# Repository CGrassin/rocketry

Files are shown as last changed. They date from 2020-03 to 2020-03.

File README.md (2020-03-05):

# Charleslab's rocketery

Thrust vectoring is the ability of an aircraft, rocket, or other vehicle to manipulate the direction of the thrust from its motor in order to control the attitude (angle) of the vehicle. It is used in rocketry it is the primary means of attitude control, as aerodynamic control surfaces are ineffective outside the atmosphere.

This repository contains all resources for my model rocketery experiments. The content of each folder is described hereunder.

Everything is work in progress (currently working on the code and the gimbal).

## 3D models

This folder contains the 3D models for my rocket:
* The 2 axes thrust vectoring control (TVC) gimbal (SolidWorks),
* The gimbal test stand (OpenSCAD parametric design),
* The PCB holder (OpenSCAD parametric design),
* The nose cone (OpenSCAD parametric design).

TODO : add render of all models

The gimbal is a 3D-printable, parametric Solidworks model. There are two variables that should be adjusted to fit your needs: the diameter of the rocket motor and the diameter of the rocket body. The geometry adapts to these constraints. It should be 3D-printed with supports enabled.

TODO : add photo

The cone is a work-in-progress parametric openSCAD model.

## Electronics

The "Sagan" PCB is my rocket's onboard computer. It features:
* Arduino Mini (ATMega328P at 3.3v),
* BMP280 barometer,
* MPU6050 gyroscope and accelerometer,
* Micro SD Card reader to store in-flight telemetry,
* 3 servo outputs (X, Y and extra),
* 2 pyro channels (PYRO0 and PYRO1),
* LED and buzzer.

TODO : add picture

Designed in KiCad.

## Code

This folder contains the Arduino code for the "Sagan" PCB.

To tune and test the controller, I made a Java gimbaled rocket simulator: http://charleslabs.fr/en/project-Gimbaled+Model+Rocket+Simulator

## Flight data

This folder holds the data (telemetry) for each flight of the rocket.

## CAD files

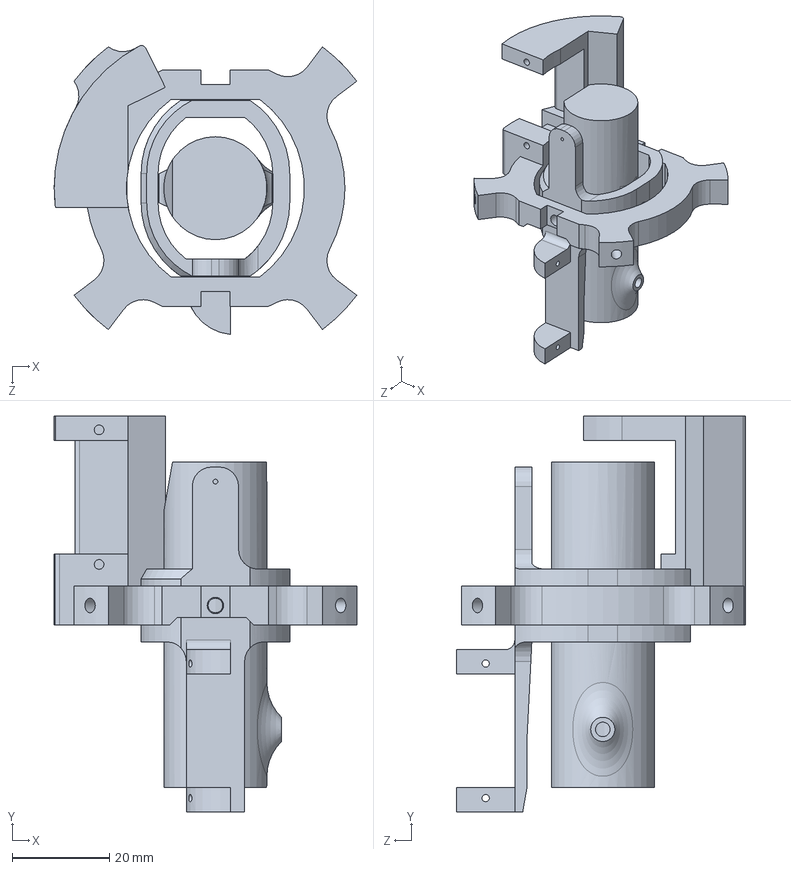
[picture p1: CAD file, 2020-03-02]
3D_models/KeplerMK1_TVC.SLDPRT
62.3 x 81.5 x 59.5 mm

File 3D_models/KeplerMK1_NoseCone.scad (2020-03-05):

/**
* Nose cones for model rockets.
*
* Units: mm
*
* CGrassin, 2020, MIT License, based on
* NOSE CONE LIBRARY, version 1.0
* by Garrett Goss, 2015, published 9/16, public domain.
**/

// --- Settings ---
rocket_diameter = 73;
c_factor = 0/3;
cone_length = 100;
base_length=8;

cylinder(base_length,d=rocket_diameter,$fn=500);
translate([0, 0,base_length]) cone_haack(C = c_factor, R = rocket_diameter/2, L = cone_length - base_length, s = 200);

// --- Code ---
module cone_cone(R = 5, L = 10, s = 500){
// CONICAL NOSE CONE
//
// Formula: y = x * R / L; 
//
//     but there's an easier way...

echo(str("CONICAL NOSE CONE"));    
echo(str("R = ", R)); 
echo(str("L = ", L)); 
echo(str("s = ", s)); 

cylinder(h = L, r1 = R, r2 = 0, center = false, $fn = s);
    
}

module cone_blunted(R = 5, R_nose = 2, L = 15, s = 500){
// SPHERICALLY BLUNTED CONE
//     A conical nose capped with a segment of a sphere
//

echo(str("SPHERICALLY BLUNTED CONE"));
echo(str("R = ", R));
echo(str("R_nose = ", R_nose)); 
echo(str("L = ", L));
echo(str("s = ", s)); 
    
x_t = (pow(L,2) / R) * sqrt(pow(R_nose,2) / (pow(R,2) + pow(L,2)));
y_t = x_t * (R/L);
x_o = x_t + sqrt(pow(R_nose,2) - pow(y_t,2));
x_a = x_o - R_nose;

TORAD = PI/180;
TODEG = 180/PI;
inc = 1/s;
    
s_x_t = round((s * x_t) / L);

rotate_extrude(convexity = 10, $fn = s)
union(){
    for (i = [s_x_t : s]){

        x_last = L * (i - 1) * inc;
        x = L * i * inc;

        y_last = x_last * (R/L);

        y = x * (R / L);

        rotate([0, 0, -90]) polygon(points = [[x_last - L, 0], [x - L, 0], [x - L, y], [x_last - L, y_last]], convexity = 10);
    }

    translate([0, L-x_o, 0]) difference(){
        circle(R_nose, $fn = s);
        translate([-R_nose, 0, 0]) square((2 * R_nose), center = true);
    }
}
}
        
module cone_parabolic(R = 5, L = 10, K = 0.5, s = 500){
// PARABOLIC NOSE CONE
//
// Formula: y = R * ((2 * (x / L)) - (K * pow((x / L),2)) / (2 - K);
//
// Parameters:
// K = 0 for cone
// K = 0.5 for 1/2 parabola
// K = 0.75 for 3/4 parabola
// K = 1 for full parabola

echo(str("PARABOLIC NOSE CONE"));
echo(str("R = ", R)); 
echo(str("L = ", L)); 
echo(str("K = ", K)); 
echo(str("s = ", s)); 
    
if (K >= 0 && K <= 1){

    inc = 1/s;

    rotate_extrude(convexity = 10, $fn = s)
    for (i = [1 : s]){
        
        x_last = L * (i - 1) * inc;
        x = L * i * inc;

        y_last = R * ((2 * ((x_last)/L)) - (K * pow(((x_last)/L), 2))) / (2 - K);
        y = R * ((2 * (x/L)) - (K * pow((x/L), 2))) / (2 - K);

        polygon(points = [[y_last, 0], [y, 0], [y, L - x], [y_last, L - x_last]], convexity = 10);
    }
} else echo(str("ERROR: K = ", K, ", but K must fall between 0 and 1 (inclusive)."));
}

module cone_haack(C = 0, R = 5, L = 10, s = 500){

// SEARS-HAACK BODY NOSE CONE:
//
// Parameters:
// C = 1/3: LV-Haack (minimizes supersonic drag for a given L & V)
// C = 0: LD-Haack (minimizes supersonic drag for a given L & D), also referred to as Von Kármán
//
// Formulae (radians):
// theta = acos(1 - (2 * x / L));
// y = (R / sqrt(PI)) * sqrt(theta - (sin(2 * theta) / 2) + C * pow(sin(theta),3));

echo(str("SEARS-HAACK BODY NOSE CONE"));
echo(str("C = ", C)); 
echo(str("R = ", R)); 
echo(str("L = ", L)); 
echo(str("s = ", s)); 

TORAD = PI/180;
TODEG = 180/PI;

inc = 1/s;

rotate_extrude(convexity = 10, $fn = s)
for (i = [1 : s]){
    x_last = L * (i - 1) * inc;
    x = L * i * inc;

    theta_last = TORAD * acos((1 - (2 * x_last/L)));
    y_last = (R/sqrt(PI)) * sqrt(theta_last - (sin(TODEG * (2*theta_last))/2) + C * pow(sin(TODEG * theta_last), 3));

    theta = TORAD * acos(1 - (2 * x/L));
    y = (R/sqrt(PI)) * sqrt(theta - (sin(TODEG * (2 * theta)) / 2) + C * pow(sin(TODEG * theta), 3));

    rotate([0, 0, -90]) polygon(points = [[x_last - L, 0], [x - L, 0], [x - L, y], [x_last - L, y_last]], convexity = 10);
}
}


module cone_power_series(n = 0.5, R = 5, L = 10, s = 500){
// POWER SERIES NOSE CONE:
//
// Formula: y = R * pow((x / L), n) for 0 <= n <= 1
//
// Parameters:
// n = 1 for a cone
// n = 0.75 for a 3/4 power
// n = 0.5 for a 1/2 power (parabola)
// n = 0 for a cylinder

echo(str("POWER SERIES NOSE CONE"));
echo(str("n = ", n)); 
echo(str("R = ", R)); 
echo(str("L = ", L)); 
echo(str("s = ", s)); 

inc = 1/s;

rotate_extrude(convexity = 10, $fn = s)
for (i = [1 : s]){

    x_last = L * (i - 1) * inc;
    x = L * i * inc;

    y_last = R * pow((x_last/L), n);
    y = R * pow((x/L), n);

    rotate([0, 0, 90]) polygon(points = [[0,y_last],[0,y],[L-x,y],[L-x_last,y_last]], convexity = 10);
}
}

module cone_elliptical(n = 0.5, R = 5, L = 10, s = 500){
// ELLIPTICAL NOSE CONE:
//
// Formula: y = R * sqrt(1 - pow((x / L), 2));

echo(str("ELLIPTICAL NOSE CONE"));    
echo(str("n = ", n)); 
echo(str("R = ", R)); 
echo(str("L = ", L)); 
echo(str("s = ", s)); 

inc = 1/s;

rotate_extrude(convexity = 10, $fn = s)
for (i = [1 : s]){

    x_last = L * (i - 1) * inc;
    x = L * i * inc;

    y_last = R * sqrt(1 - pow((x_last/L), 2));
    y = R * sqrt(1 - pow((x/L), 2));

    rotate([0,0,90]) polygon(points = [[0, y_last], [0, y], [x, y], [x_last, y_last]], convexity = 10);
}
}
module cone_ogive_sec(rho = 8, R = 5, L = 10, s = 500){
// SECANT OGIVE NOSE CONE:
//
// For a bulging cone (e.g. Honest John): L/2 < rho < (R^2 + L^2)/(2R)
// Otherwise: rho > (R^2 + L^2)/(2R)
//
// Formulae:
// alpha = TORAD * atan(R/L) - TORAD * acos(sqrt(pow(L,2) + pow(R,2)) / (2 * rho));
// y = sqrt(pow(rho,2) - pow((rho * cos(TODEG * alpha) - x),2)) + (rho * sin(TODEG * alpha));

echo(str("SECANT OGIVE NOSE CONE"));    
echo(str("rho = ", rho)); 
echo(str("R = ", R)); 
echo(str("L = ", L)); 
echo(str("s = ", s)); 

TORAD = PI/180;
TODEG = 180/PI;
    
inc = 1/s;

alpha = TORAD * atan(R/L) - TORAD * acos(sqrt(pow(L,2) + pow(R,2)) / (2*rho));

rotate_extrude(convexity = 10, $fn = s)
for (i = [1 : s]){

    x_last = L * (i - 1) * inc;
    x = L * i * inc;

    y_last = sqrt(pow(rho,2) - pow((rho * cos(TODEG*alpha) - x_last), 2)) + (rho * sin(TODEG*alpha));

    y = sqrt(pow(rho,2) - pow((rho * cos(TODEG*alpha) - x), 2)) + (rho * sin(TODEG*alpha));

    rotate([0, 0, -90]) polygon(points = [[x_last - L, 0], [x - L, 0], [x - L, y], [x_last - L, y_last]], convexity = 10);
}
}


module cone_ogive_tan(R = 5, L = 10, s = 500){
// TANGENT OGIVE
//
//

echo(str("TANGENT OGIVE"));    
echo(str("R = ", R)); 
echo(str("L = ", L)); 
echo(str("s = ", s)); 

rho = (pow(R,2) + pow(L,2)) / (2 * R);

inc = 1/s;

rotate_extrude(convexity = 10, $fn = s)
for (i = [1 : s]){
    x_last = L * (i - 1) * inc;
    x = L * i * inc;

    y_last = sqrt(pow(rho,2) - pow((L - x_last), 2)) + R - rho;

    y = sqrt(pow(rho,2) - pow((L - x), 2)) + R - rho;

    rotate([0, 0, -90]) polygon(points = [[x_last - L, 0], [x - L, 0], [x - L, y], [x_last - L, y_last]], convexity = 10);
}
}

module cone_ogive_tan_blunted(R_nose = 2, R = 5, L = 10, s = 500){
// SPHERICALLY BLUNTED TANGENT OGIVE
//
//

echo(str("SPHERICALLY BLUNTED TANGENT OGIVE"));    
echo(str("R_nose = ", R_nose)); 
echo(str("R = ", R)); 
echo(str("L = ", L)); 
echo(str("s = ", s)); 

rho = (pow(R,2) + pow(L,2)) / (2*R);

x_o = L - sqrt(pow((rho - R_nose), 2) - pow((rho - R), 2));
x_a = x_o - R_nose;
y_t = (R_nose * (rho - R)) / (rho - R_nose);
x_t = x_o - sqrt(pow(R_nose, 2)- pow(y_t, 2));

TORAD = PI/180;
TODEG = 180/PI;
    
inc = 1/s;
    
s_x_t = round((s * x_t) / L);

alpha = TORAD * atan(R/L) - TORAD * acos(sqrt(pow(L,2) + pow(R,2)) / (2*rho));

rotate_extrude(convexity = 10, $fn = s) union(){
    for (i=[s_x_t:s]){

        x_last = L * (i - 1) * inc;
        x = L * i * inc;

        y_last = sqrt(pow(rho,2) - pow((rho * cos(TODEG * alpha) - x_last),2)) + (rho * sin(TODEG * alpha));

        y = sqrt(pow(rho,2) - pow((rho * cos(TODEG * alpha) - x),2)) + (rho * sin(TODEG * alpha));

        rotate([0,0,-90])polygon(points = [[x_last-L,0],[x-L,0],[x-L,y],[x_last-L,y_last]], convexity = 10);
    }

    translate([0, L - x_o, 0]) difference(){
        circle(R_nose, $fn = s);
        translate([-R_nose, 0, 0]) square((2 * R_nose), center = true);
    }
}
}

module cone_biconic(R = 5, R_nose = 3, L1 = 6, L2 = 4, s = 500){

echo(str("BICONIC NOSE CONE")); 
echo(str("R = ", R));    
echo(str("R_nose = ", R_nose)); 
echo(str("L1 = ", L1));
echo(str("L2 = ", L2)); 
echo(str("s = ", s)); 
    
L = L1 + L2;
s_intermediate = s * (L2/L);
inc = 1/s;

rotate_extrude(convexity = 10, $fn = s) translate([0, L, 0]) rotate([0, 0, -90])
union(){
    for (i = [1 : s_intermediate]){

        x_last = L * (i - 1) * inc;
        x = L * i * inc;

        y_last = x_last * (R_nose/L2);
        y = x * (R_nose/L2);

        polygon(points = [[x_last, 0], [x_last, y_last], [x, y], [x, 0]], convexity = 10);
    }
    
    for (i=[s_intermediate:s]){

        x_last = L * (i - 1) * inc;
        x = L * i * inc;

        y_last = R_nose + ((x_last - L2) * (R - R_nose)) / L1;
        y = R_nose + ((x - L2) * (R - R_nose)) / L1;
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

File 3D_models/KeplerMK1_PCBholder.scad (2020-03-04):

/**
* PCB holder for model rockets.
* Use with "Sagan" PCB.
*
* Units: mm
*
* CGrassin, 2020, MIT License
**/

// --- Settings ---
// Inside diameter of the rocket's body (in mm).
rocket_diameter = 70;

// --- Code ---
rocket_PCB_holder(rocket_diameter);


module rocket_PCB_holder(rocket_diameter) {
    // --- Internal variables ---
    //PCB
    PCB_holes_diameter = 3.2;
    PCB_holes_spacing = 32.51;
    //Ring
    ring_width = 1.5;
    ring_heigth = 6;
    //Screw blocks
    screw_block_nb = 2;
    screw_block_width = 5;
    screw_block_taper = 2.5;
    screw_block_length = 6;
    screw_block_diameter = 3;

    // --- Computed variables ---
    a = sqrt(pow(rocket_diameter/2,2)-pow((screw_block_width+2*screw_block_taper)/2,2))-screw_block_length/2;

    // Ring
    difference() {
        union(){
            // Main tube
            difference() {
                cylinder(ring_heigth,d=rocket_diameter,center=true,$fn=200);
                cylinder(ring_heigth+1,d=rocket_diameter-ring_width*2,center=true,$fn=200);
            }
            
            // Screw blocks
           for(i = [0:360/screw_block_nb:360]) rotate([0, 0, i]) 
               translate([0,a,0]) 
               linear_extrude(ring_heigth,center=true)
               translate([-screw_block_width/2,-screw_block_length/2,0]) 
               polygon(points=[[0,0],[-screw_block_taper,screw_block_length],[screw_block_width+screw_block_taper,screw_block_length],[screw_block_width,0]]);
        }
        
        // Screw blocks hole
        for(i = [0:360/screw_block_nb:360]) rotate([0, 0, i]) translate([0,a,0]) rotate([90, 0, 0]) cylinder(screw_block_length+3, d=screw_block_diameter, $fn=20, center=true);
    }

    // Central bar
    difference() {
        cube([rocket_diameter, ring_width, ring_heigth],center=true);
        
        for(i = [-PCB_holes_spacing/2,PCB_holes_spacing/2])
            translate([i,0,0]) rotate([90, 0, 0]) cylinder(ring_width+1,d=PCB_holes_diameter,$fn=100,center=true);
    }
}

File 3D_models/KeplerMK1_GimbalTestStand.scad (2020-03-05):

/**
* Gimbal test stand for model rockets.
*
* Units: mm
*
* CGrassin, 2020, MIT License
**/

// --- Settings ---
// Inside diameter of the rocket's body (in mm).
rocket_diameter = 70;

// --- Code ---
rocket_test_stand(rocket_diameter);

module rocket_test_stand(rocket_diameter,stand_height=55,base_screw_holes=true) {
    // Internal variables
    stand_width = 3;
    stand_base_height = 2;
    stand_base_diameter = stand_width + 15;
    stand_taper_base = 2;
    screw_holes_dia = 3.2;
    
    difference(){
        // Main body (tube)
        union(){
            // Main truncated cone shape
            cylinder(stand_height, d1=rocket_diameter+stand_width+stand_taper_base*2,d2=rocket_diameter+stand_width,$fn=200);
            
            // Base ring
            cylinder(stand_base_height, d=rocket_diameter+stand_base_diameter,$fn=200);
            
            // Chamfer
            translate([0,0,stand_base_height]) cylinder(stand_base_height+10, d1=rocket_diameter+stand_base_diameter,d2=rocket_diameter,$fn=200);
        }
        // Inside
        cylinder(stand_height+1, d=rocket_diameter,$fn=100);
        
        // Gimbal screw holes
        for(i = [0:90:360])
        rotate([0,0,i]) translate([0, 0, stand_height-1.5*screw_holes_dia]) rotate([0, 90, 0]) cylinder(rocket_diameter, d=screw_holes_dia,$fn=20);
        
        // Remove side material
        cut = rocket_diameter/3.2;
        for(i = [45:90:360]) translate([0,0,stand_base_height]) rotate([0, -90, i]) linear_extrude(rocket_diameter) polygon([[0,-cut],[0,cut],[stand_height,cut],[stand_height,-cut]]);
        
        // Base screw holes
        if(base_screw_holes) {
            for(i = [45:90:360]) rotate([0,0,i]) translate([(rocket_diameter+stand_base_diameter/2)/2,0,0]) cylinder(stand_base_height,d=screw_holes_dia,$fn=20);
        }
    }
}

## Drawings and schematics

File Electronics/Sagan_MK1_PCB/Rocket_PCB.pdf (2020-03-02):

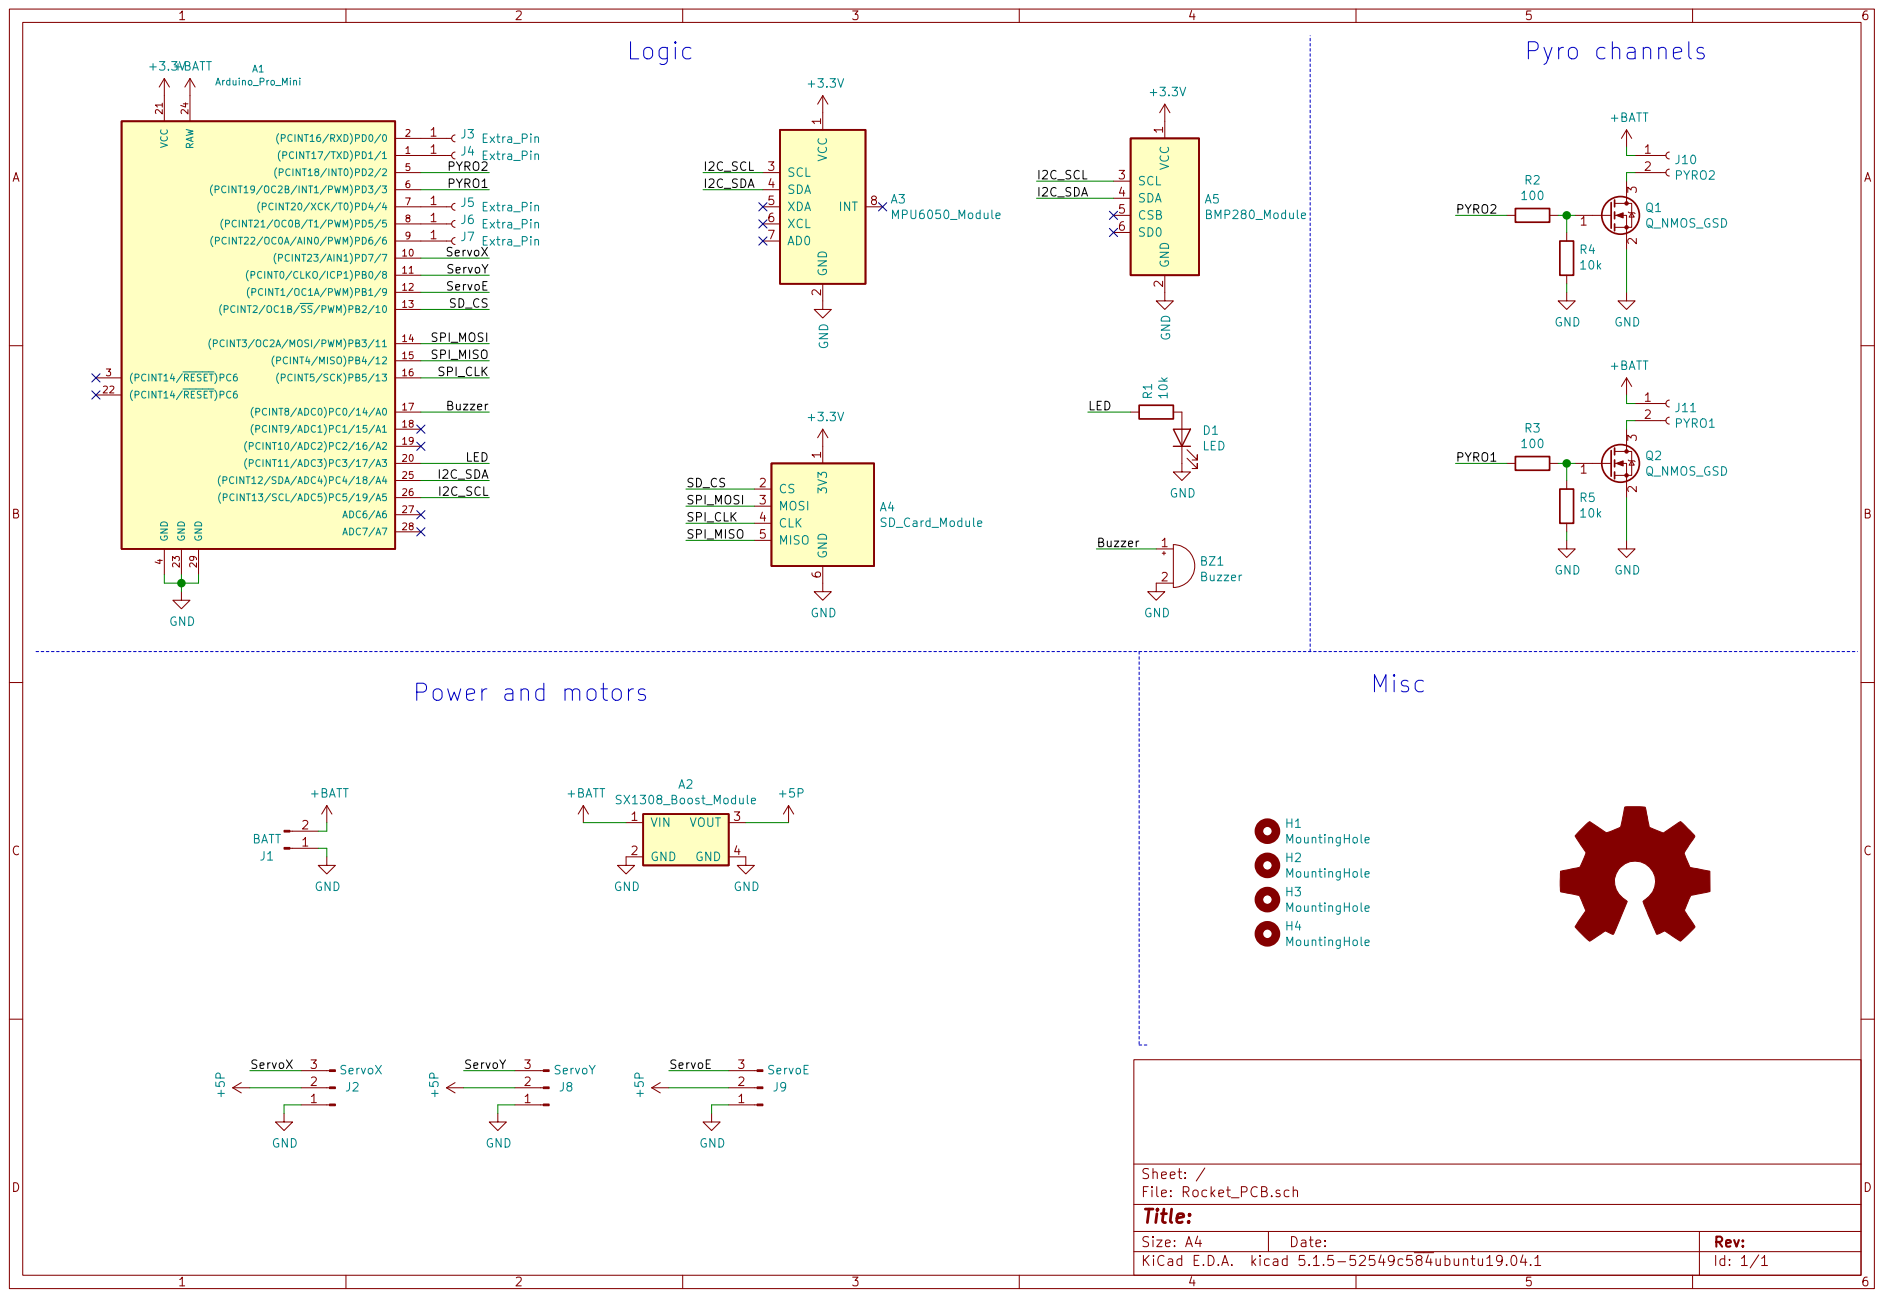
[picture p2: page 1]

6 A4SD_Card_Module VIN 1 GND 2 VOUT 3 GND 4 A2 SX1308_Boost_Module VCC

2 SCL 3 SDA 4 CSB 5 SD0 6 A5BMP280_Module +5P GND

2 SCL 3 SDA 4 XDA 5 XCL 6 AD0 7

1 CS 2 MOSI 3 CLK 4 MISO 5 GND

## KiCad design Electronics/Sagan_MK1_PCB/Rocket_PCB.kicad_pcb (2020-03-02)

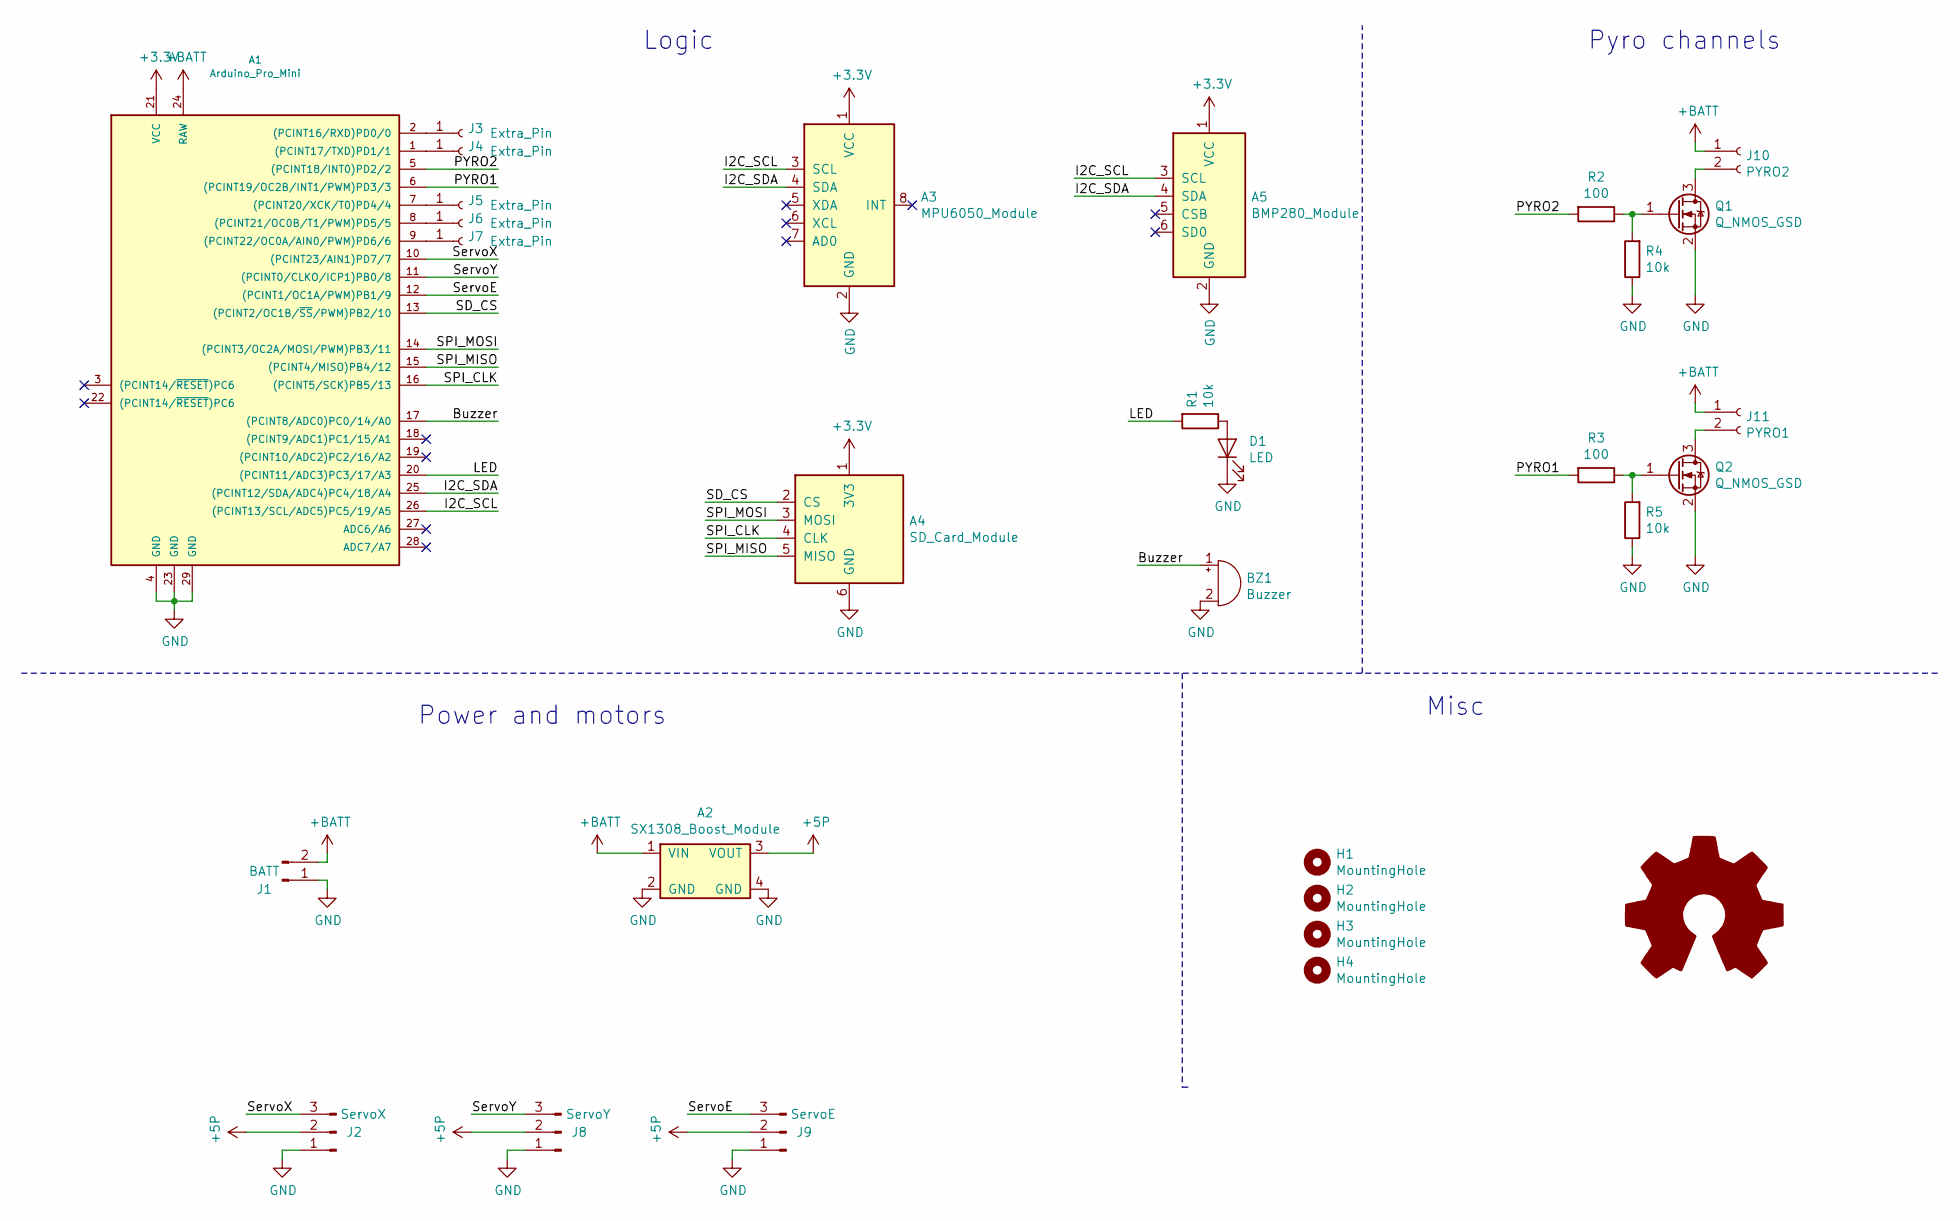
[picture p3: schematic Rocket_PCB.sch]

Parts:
A1: Arduino_Pro_Mini; Arduino_Pro_Mini_China
A2: SX1308_Boost_Module
A3: MPU6050_Module
A4: SD_Card_Module
A5: BMP280_Module
BZ1: Buzzer; Buzzer_12x9.5RM7.6
D1: LED; LED_0805_2012Metric
H1, H2, H3, H4: MountingHole; MountingHole_3.2mm_M3
J1: BATT; PinHeader_1x02_P2.54mm_Vertical
J2: ServoX; PinHeader_1x03_P2.54mm_Vertical
J3, J4, J5, J6, J7: Extra_Pin; PinHeader_1x01_P2.54mm_Vertical
J8: ServoY; PinHeader_1x03_P2.54mm_Vertical
J9: ServoE; PinHeader_1x03_P2.54mm_Vertical
J10: PYRO2; TerminalBlock_TE_282834-2_1x02_P2.54mm_Horizontal
J11: PYRO1; TerminalBlock_TE_282834-2_1x02_P2.54mm_Horizontal
LOGO1: Logo_Open_Hardware_Large; Charleslabs_Logo_5mm
Q1, Q2: Q_NMOS_GSD; SOT-23
R1, R4, R5: 10k; R_0805_2012Metric
R2, R3: 100; R_0805_2012Metric

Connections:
+3V3: A1.21 (VCC), A3.1 (VCC), A4.1 (3V3), A5.1 (VCC)
+5P: A2.3 (VOUT), J2.2, J8.2, J9.2
+BATT: A1.24 (RAW), A2.1 (VIN), J1.2, J10.1, J11.1
/Buzzer: A1.17 ((PCINT8/ADC0)PC0/14/A0), BZ1.1 (-)
/I2C_SCL: A1.26 ((PCINT13/SCL/ADC5)PC5/19/A5), A3.3 (SCL), A5.3 (SCL)
/I2C_SDA: A1.25 ((PCINT12/SDA/ADC4)PC4/18/A4), A3.4 (SDA), A5.4 (SDA)
/LED: A1.20 ((PCINT11/ADC3)PC3/17/A3), R1.2
/PYRO1: A1.6 ((PCINT19/OC2B/INT1/PWM)PD3/3), R3.2
/PYRO2: A1.5 ((PCINT18/INT0)PD2/2), R2.2
/SD_CS: A1.13 ((PCINT2/OC1B/~SS~/PWM)PB2/10), A4.2 (CS)
/SPI_CLK: A1.16 ((PCINT5/SCK)PB5/13), A4.4 (CLK)
/SPI_MISO: A1.15 ((PCINT4/MISO)PB4/12), A4.5 (MISO)
/SPI_MOSI: A1.14 ((PCINT3/OC2A/MOSI/PWM)PB3/11), A4.3 (MOSI)
/ServoE: A1.12 ((PCINT1/OC1A/PWM)PB1/9), J9.3
/ServoX: A1.10 ((PCINT23/AIN1)PD7/7), J2.3
/ServoY: A1.11 ((PCINT0/CLKO/ICP1)PB0/8), J8.3
GND: A1.4 (GND), A1.23 (GND), A1.29 (GND), A2.2 (GND), A2.4 (GND), A3.2 (GND), A4.6 (GND), A5.2 (GND), BZ1.2 (+), D1.1 (K), J1.1, J2.1, J8.1, J9.1, Q1.2 (S), Q2.2 (S), R4.1, R5.1
unnamed: A1.1 ((PCINT17/TXD)PD1/1), J4.1
unnamed: A1.2 ((PCINT16/RXD)PD0/0), J3.1
unnamed: A1.7 ((PCINT20/XCK/T0)PD4/4), J5.1
unnamed: A1.8 ((PCINT21/OC0B/T1/PWM)PD5/5), J6.1
unnamed: A1.9 ((PCINT22/OC0A/AIN0/PWM)PD6/6), J7.1
unnamed: D1.2 (A), R1.1
unnamed: J10.2, Q1.3 (D)
unnamed: J11.2, Q2.3 (D)
unnamed: Q1.1 (G), R2.1, R4.2
unnamed: Q2.1 (G), R3.1, R5.2

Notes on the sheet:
Logic
Pyro channels
Power and motors
Misc

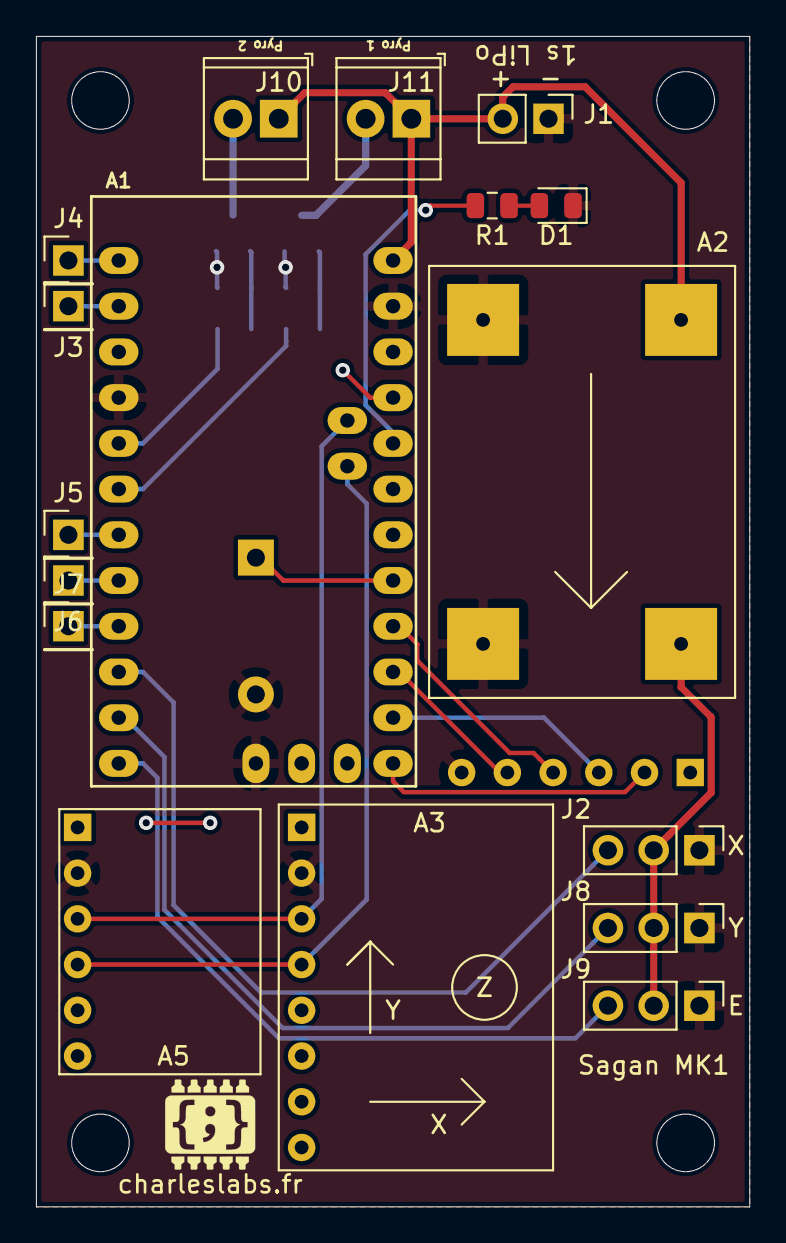
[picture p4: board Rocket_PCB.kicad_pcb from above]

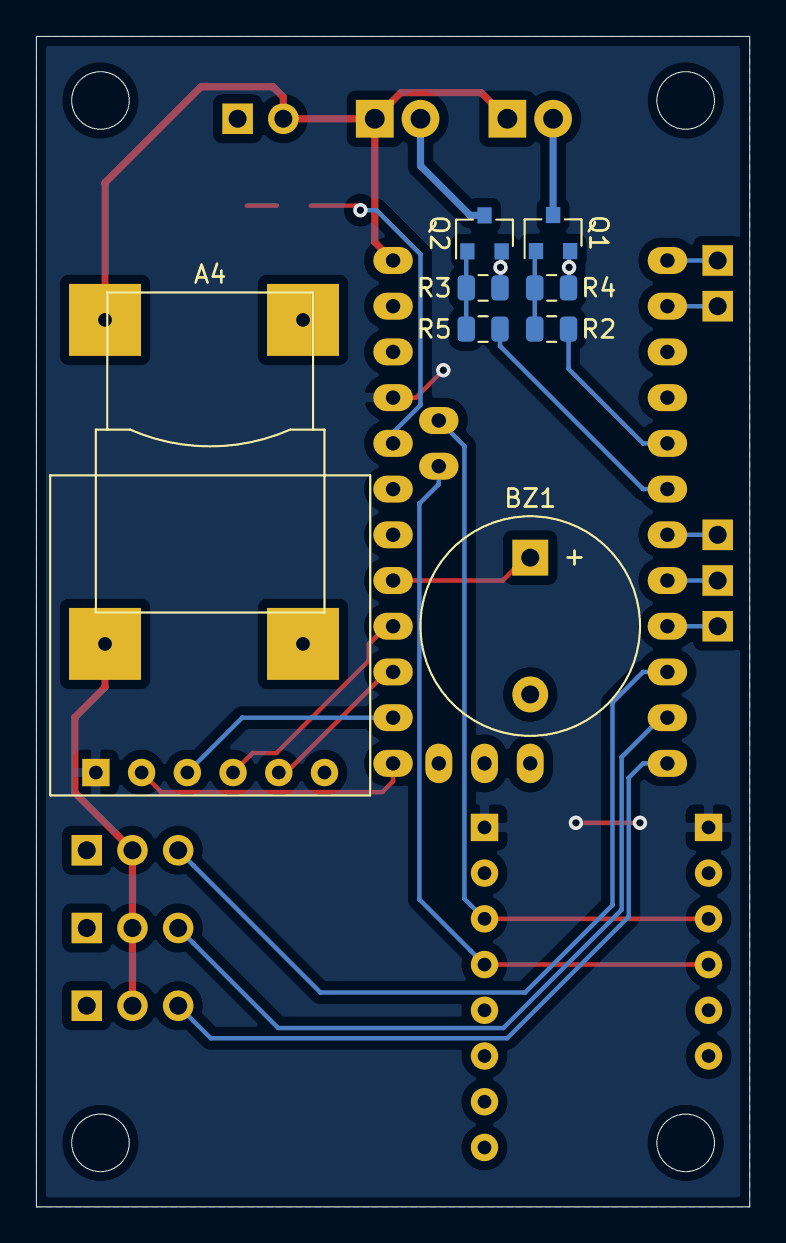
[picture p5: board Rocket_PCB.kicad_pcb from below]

Board: 2 copper layers, 39.6 x 65.0 mm, 30 parts (8 on the bottom side), 27 nets.

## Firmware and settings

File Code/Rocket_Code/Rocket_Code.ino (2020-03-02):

/**
 * Designed for Sagan MK1 PCB using 
 * Arduino Pro Mini with 328P at 8MHz/3.3V.
 * 
 * Charles GRASSIN, 2019
 * MIT License
 */

// Libs
#include "PID.h"
#include "MPU6050.h"
#include "BMP280.h"
#include <Servo.h>
#include <SPI.h>
#include <SD.h>


// PINS (for the Sagan MK1 PCB)
#define PIN_PYRO_1 (2)
#define PIN_PYRO_2 (3)
#define PIN_SERVO_X (7)
#define PIN_SERVO_Y (8)
#define PIN_SERVO_E (9)
#define PIN_BUZZER (A0)
#define PIN_LED (A3)
#define PIN_SD_CS (10)

// 
#define PITCH_ERROR (700)
#define PITCH_OK    (500)

// CONFIG
//#define SD_CARD_ENABLE
#define SERIAL_DEBUG_ENABLE
#define SD_CARD_FILENAME "data.csv" // Warning: 8.3 format mandatory

#define MPU6050_X_ANGLE_ERROR (-74)
#define MPU6050_Y_ANGLE_ERROR (11) // unused
#define MPU6050_Z_ANGLE_ERROR (-4)

// Global variables
Servo servo_x, servo_y;
PIDController pidx = PIDController(0,0,0), pidy = PIDController(0,0,0);
File sd_file;
uint32_t pressure;
int16_t gyroX, gyroY, gyroZ;
double angular_speed, angle_x = 0, angle_y = 0;
long timeCurrent, timePrevious;

void setup(){
  #ifdef SERIAL_DEBUG_ENABLE
    Serial.begin(115200);
  #endif
  
  // Servos
	servo_x.attach(PIN_SERVO_X);
  servo_y.attach(PIN_SERVO_Y);

  // Pyro channels
  pinMode(PIN_PYRO_1, OUTPUT);
  digitalWrite(PIN_PYRO_1, LOW);
  pinMode(PIN_PYRO_2, OUTPUT);
  digitalWrite(PIN_PYRO_2, LOW);

  // Outputs
  pinMode(PIN_BUZZER, OUTPUT);
  digitalWrite(PIN_BUZZER, LOW);
  pinMode(PIN_LED, OUTPUT);
  digitalWrite(PIN_LED, LOW);

  // MPU6050 Gyro
  if(MPU_init() == -1)
    criticalError();
  
  // BMP280 Baro
  if(BMP_init() == -1)
    criticalError();
  
  // SD card (open card and file)
  #ifdef SD_CARD_ENABLE
    if (!SD.begin(PIN_SD_CS))
      criticalError();
    sd_file = SD.open(SD_CARD_FILENAME, FILE_WRITE);
    if (!sd_file)
      criticalError();
  #endif

  // Signal ready to fligh
  #ifdef SERIAL_DEBUG_ENABLE
    Serial.println("READY!");
  #endif
  tone(PIN_BUZZER, PITCH_OK, 1000);

  timeCurrent = millis();
}

void loop(){
  // Timing
  timePrevious = timeCurrent;
  timeCurrent = millis();

  // Read sensors
  pressure = BMP_getP();
  MPU_getRawGyro(&gyroX,&gyroY,&gyroZ);

  // Compute angle
  angular_speed = (float)(gyroX - MPU6050_X_ANGLE_ERROR)/32.8;
  angle_x += angular_speed * (timeCurrent - timePrevious) / 1000.0;
  angular_speed = (float)(gyroZ - MPU6050_Z_ANGLE_ERROR)/32.8;
  angle_y += angular_speed * (timeCurrent - timePrevious) / 1000.0;

  // Servos
  servo_x.write(angle_x + 90);
  servo_y.write(angle_y + 90);
  
  #ifdef SERIAL_DEBUG_ENABLE
    Serial.print(angle_x);
    Serial.print("\t");
    Serial.println(angle_y);
  #endif
  
  #ifdef SD_CARD_ENABLE
    logSD(angle_x, angle_y);
  #endif
  delay(20);
}

void criticalError(){
  #ifdef SERIAL_DEBUG_ENABLE
    Serial.println("ERROR!");
  #endif
  
  while(1){
    tone(PIN_BUZZER, PITCH_ERROR, 200);
    delay(400);
  }
}

/*
 * Format: tab separated values. Columns:
 * - Date
 */
void logSD(float val1, float val2){
  // FIXME fill me in
  sd_file.print(millis());
  sd_file.print("\t");
  sd_file.print(val1);
  sd_file.print("\t");
  sd_file.print(val2);
  sd_file.print("\n");
  sd_file.flush();
}

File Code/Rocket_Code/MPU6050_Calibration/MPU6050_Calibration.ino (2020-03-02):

#include "MPU6050.h"

#define MEASUREMENTS_NB 100
#define MEASUREMENTS_DELAY 100

int16_t gyroX, gyroY, gyroZ;
int32_t totalX=0, totalY=0, totalZ=0;

void setup() {
  Serial.begin(115200);
  MPU_init();

  Serial.println("Measuring...");
  for(int i=0; i<MEASUREMENTS_NB;i++){
    delay(MEASUREMENTS_DELAY);
    MPU_getRawGyro(&gyroX,&gyroY,&gyroZ);
    totalX += gyroX;
    totalY += gyroY;
    totalZ += gyroZ;
  }

  Serial.println("Result:");

  Serial.print("X_error=");
  Serial.println((float)totalX/MEASUREMENTS_NB);
  
  Serial.print("Y_error=");
  Serial.println((float)totalY/MEASUREMENTS_NB);
  
  Serial.print("Z_error=");
  Serial.println((float)totalZ/MEASUREMENTS_NB);
}

void loop() {}

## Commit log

2020-03-03 Replaced PCB holder with OpenSCAD model
    [KeplerMK1_PCBholder.SLDPRT, KeplerMK1_PCBholder.scad]
2020-03-04 Improved PCB holder model
    [KeplerMK1_PCBholder.scad]
2020-03-05 Added OpenSCAD gimbal test stand
    [KeplerMK1_GimbalTestStand.scad, KeplerMK1_NoseCone.scad, KeplerMK1_Test_Stand.SLDPRT]
